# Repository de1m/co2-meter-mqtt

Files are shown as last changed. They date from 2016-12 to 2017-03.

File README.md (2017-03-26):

# CO2 Meter (mqtt)

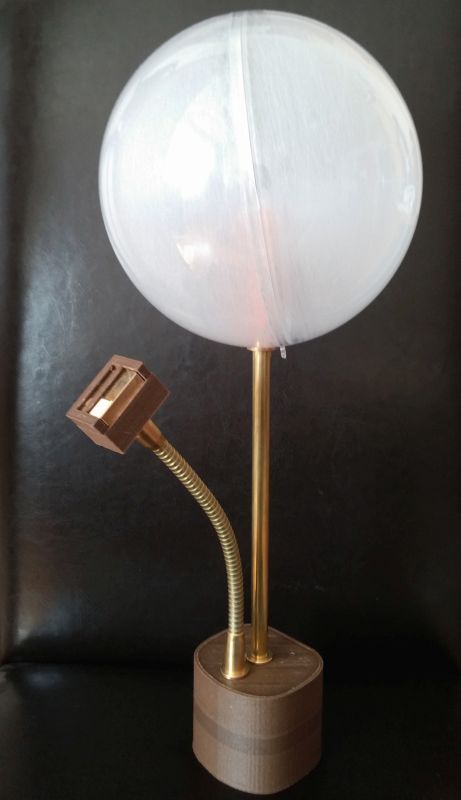
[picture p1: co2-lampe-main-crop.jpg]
main-image


## Description

In this project I've created a co2 sesor (mh-z19) with connection to a mqtt broker, so you cann send the co2 data to a mqtt broker. 

I've used the esp8266 12e version. 

Folder structure:
firmware - all files, that you do need to flash your esp8266 12e
pcb - board schema, pdfs. Imprtant: for the board you need a usb-connection board (show image board_top.jpg)
3d-models - 3d models for 3d printer, so you can print a case for pcb.

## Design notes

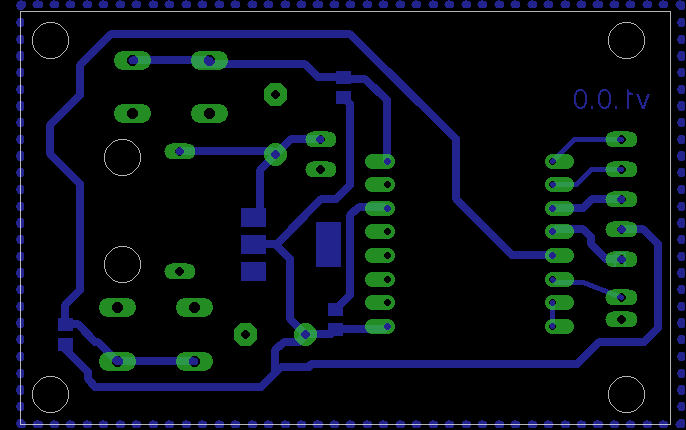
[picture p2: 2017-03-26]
pcb/board_screenshot.png

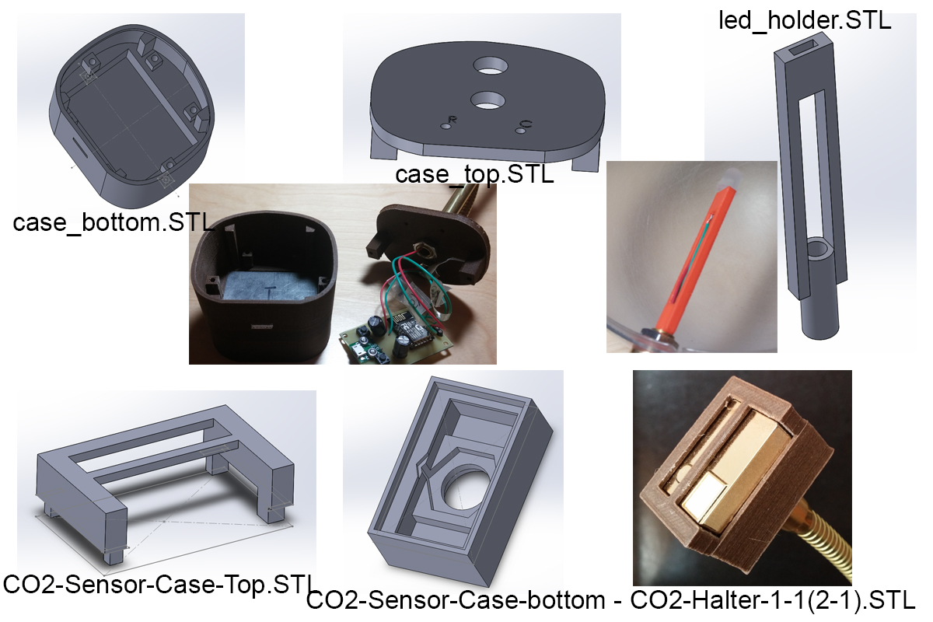
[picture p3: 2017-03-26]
3d_models/description.jpg

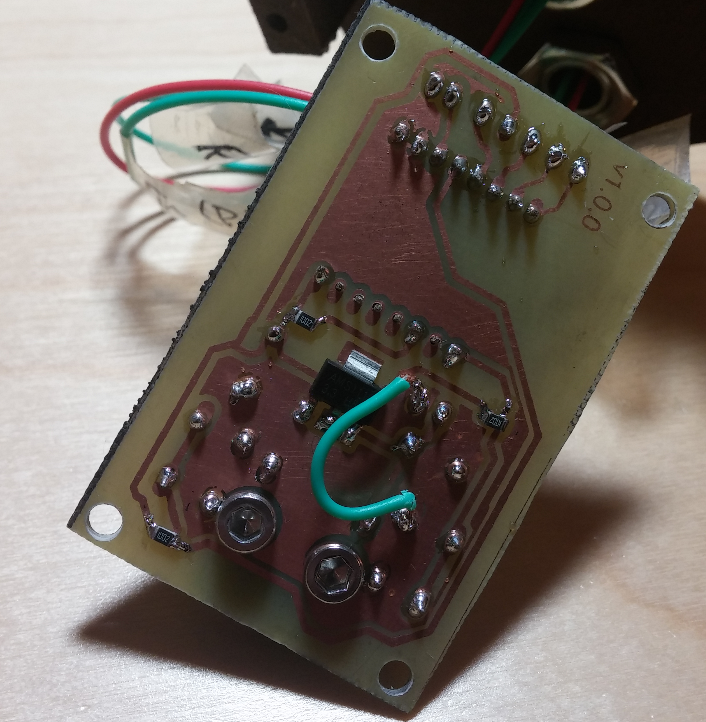
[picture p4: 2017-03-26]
pcb/board_foto_bottom.png

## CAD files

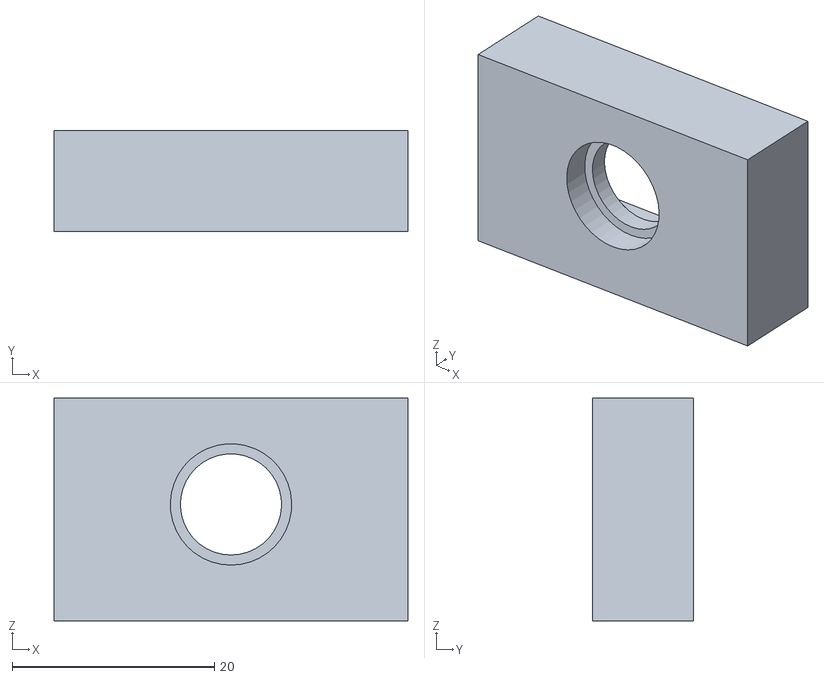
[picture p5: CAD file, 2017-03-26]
3d_models/CO2-Sensor-Case-bottom - CO2-Halter-2-1.STL
35.0 x 10.00 x 22.0

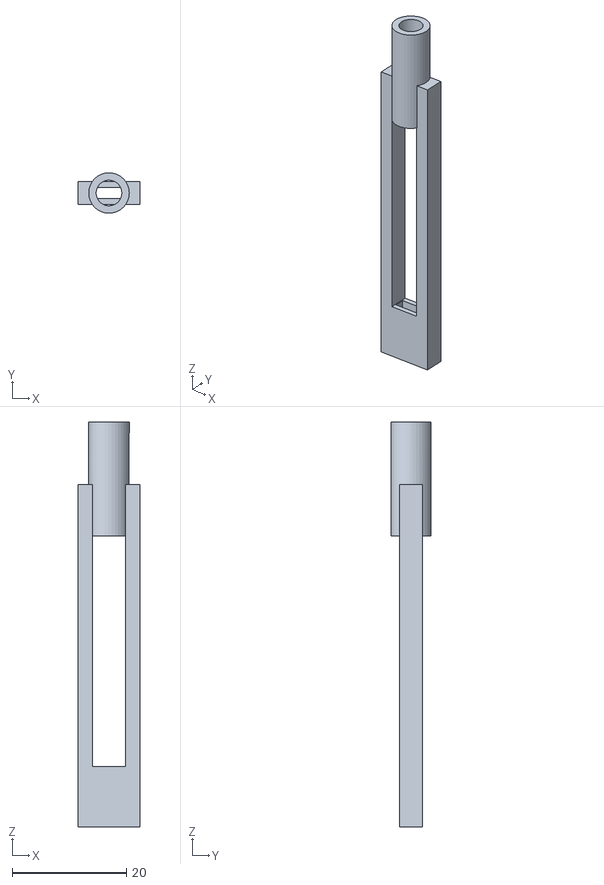
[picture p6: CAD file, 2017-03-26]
3d_models/led_holder.STL
10.9 x 7.09 x 71.0

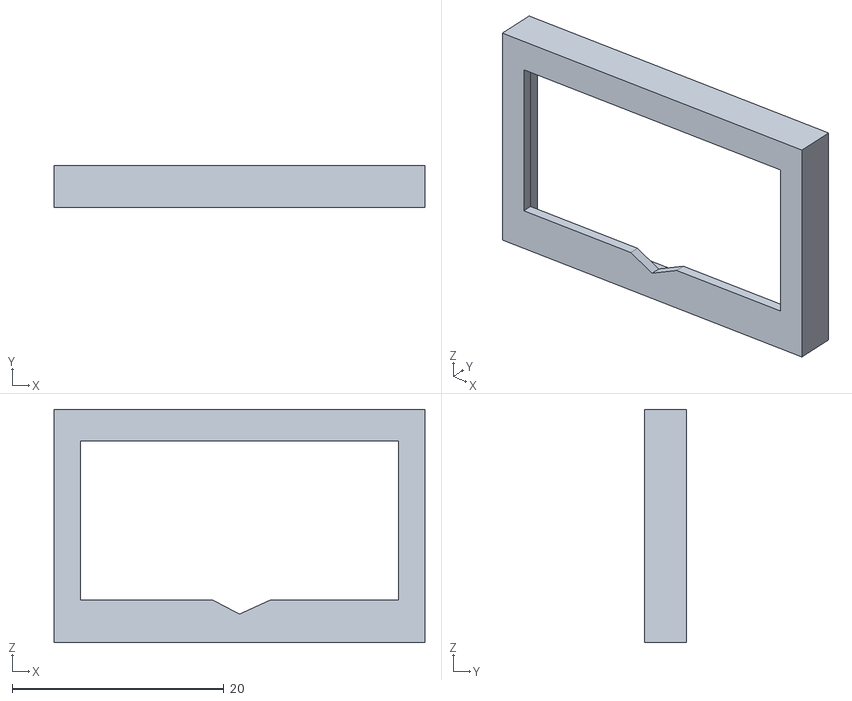
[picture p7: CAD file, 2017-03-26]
3d_models/CO2-Sensor-Case-bottom - CO2-Halter-1-1.STL
35.0 x 4.00 x 22.0

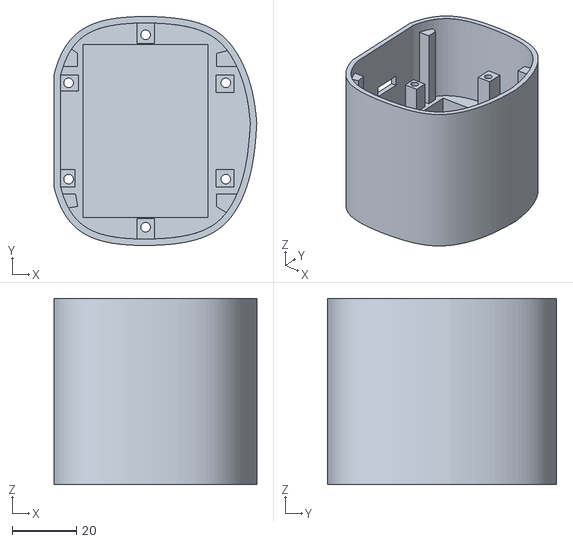
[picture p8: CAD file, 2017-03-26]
3d_models/case_bottom.STL
63.2 x 71.4 x 58.0

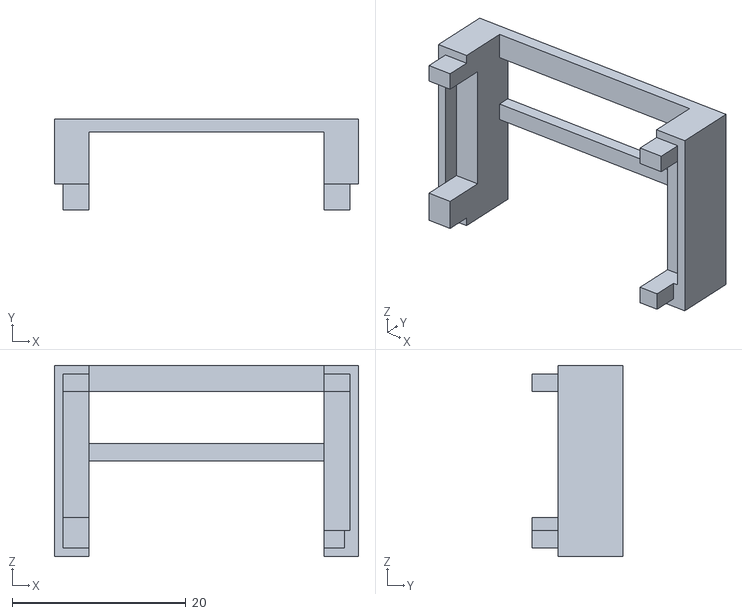
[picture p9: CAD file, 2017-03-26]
3d_models/CO2-Sensor-Case-Top.STL
35.0 x 10.5 x 22.0

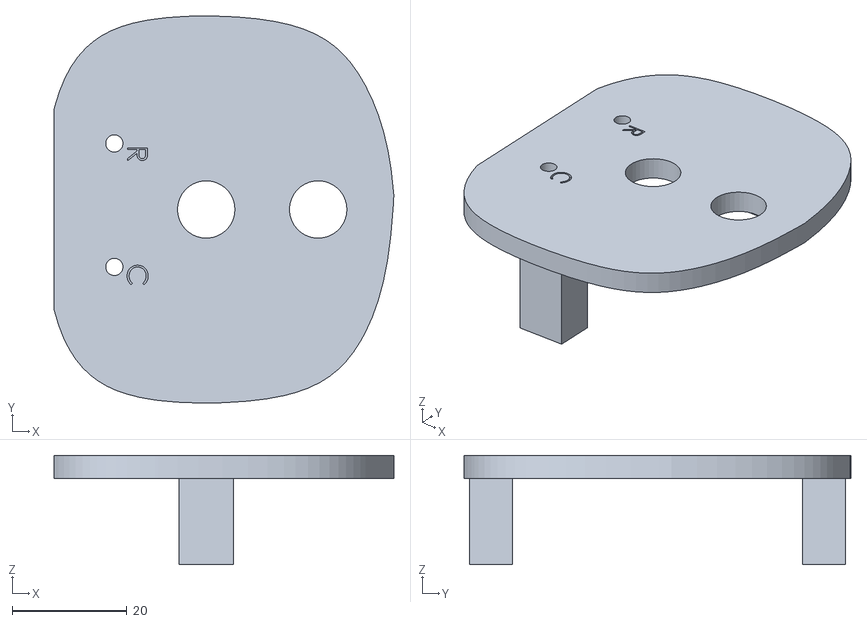
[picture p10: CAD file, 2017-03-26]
3d_models/case_top.STL
59.2 x 67.4 x 19.0

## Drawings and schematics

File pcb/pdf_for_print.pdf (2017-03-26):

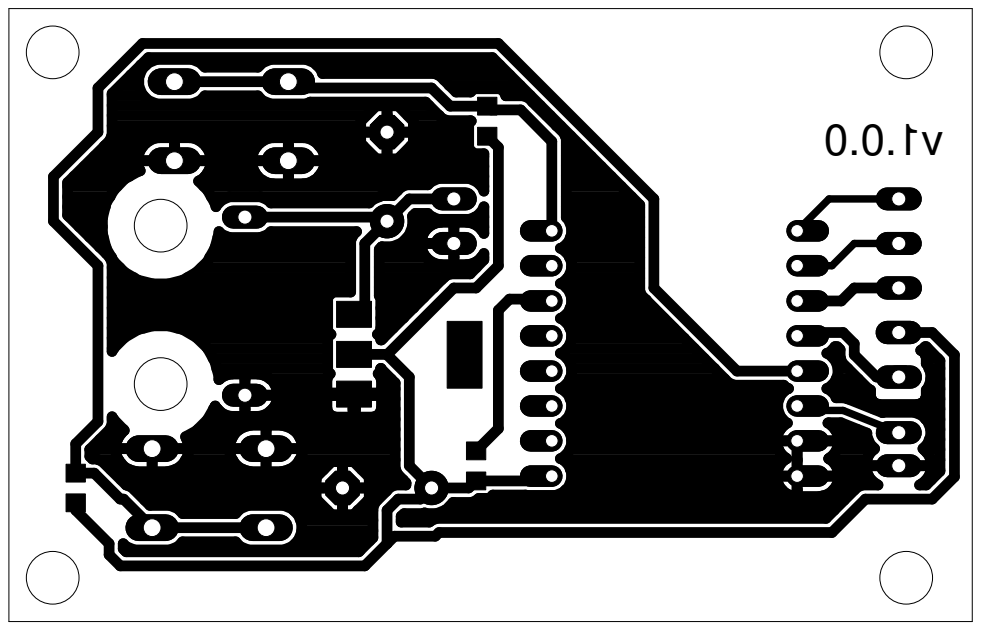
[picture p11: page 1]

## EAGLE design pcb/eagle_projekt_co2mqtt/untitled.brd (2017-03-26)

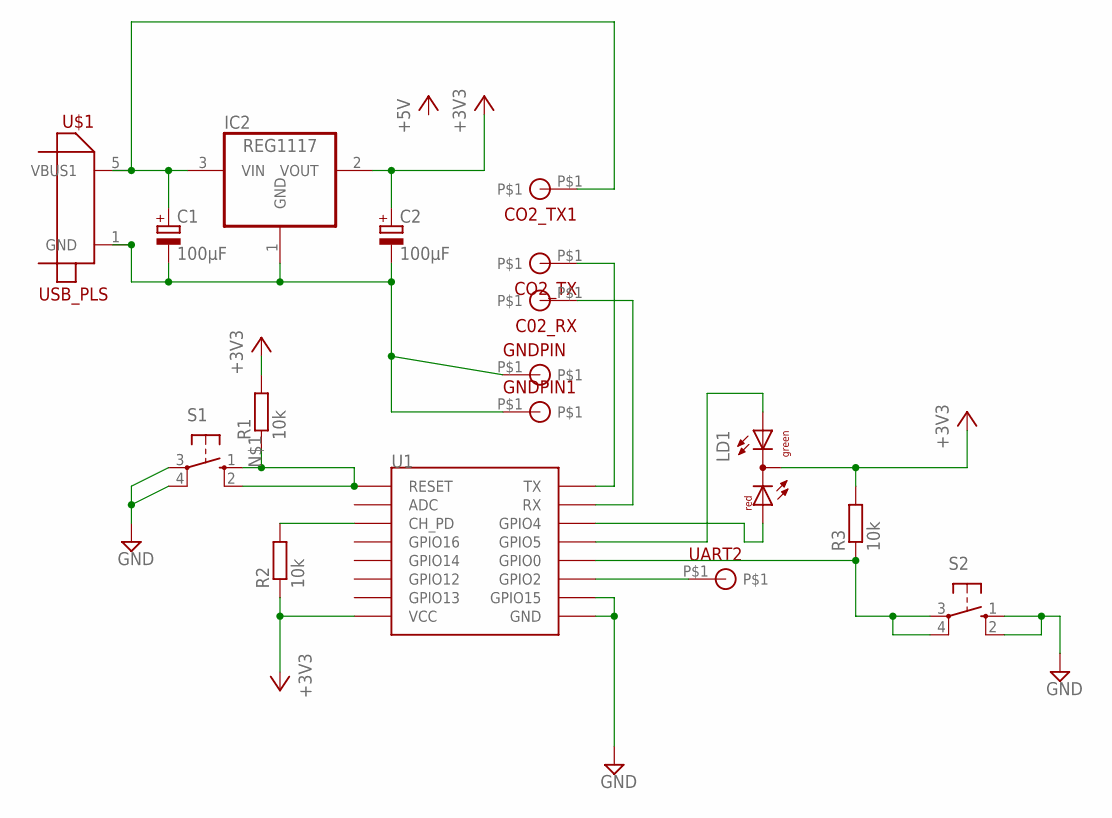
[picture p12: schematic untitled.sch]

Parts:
C1, C2: 100µF; E5-6
C02_RX: 1PIN
CO2_TX, CO2_TX1: 1PIN
GNDPIN, GNDPIN1: 1PIN
IC2: REG1117; SOT223
LD1: DUOLED-RG-C; DUOLED-C-5MM
R1, R2, R3: 10k; R0603
S1, S2: 10-XX; B3F-10XX
U1: ESP12
U$1: USB_PLS; USB_PLB
UART2: 1PIN

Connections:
+3V3: C2.+, IC2.2 (VOUT), LD1.C, R1.2, R2.1, R3.2, U1.VCC
+5V: C1.+, CO2_TX1.P$1, IC2.3 (VIN), U$1.5 (VBUS1)
GND: C1.-, C2.-, GNDPIN.P$1, GNDPIN1.P$1, IC2.1 (GND), S1.3, S1.4 (P1), S2.1 (S), S2.2 (S1), U1.GND, U1.GPIO15, U$1.1 (GND)
unnamed: R1.1, S1.1 (S), S1.2 (S1), U1.RESET
unnamed: R3.1, S2.3, S2.4 (P1), U1.GPIO0
unnamed: R2.2, U1.CH_PD
unnamed: LD1.AX (AG), U1.GPIO5
unnamed: LD1.AR, U1.GPIO4
unnamed: U1.GPIO2, UART2.P$1
RX: C02_RX.P$1, U1.RX
TX: CO2_TX.P$1, U1.TX

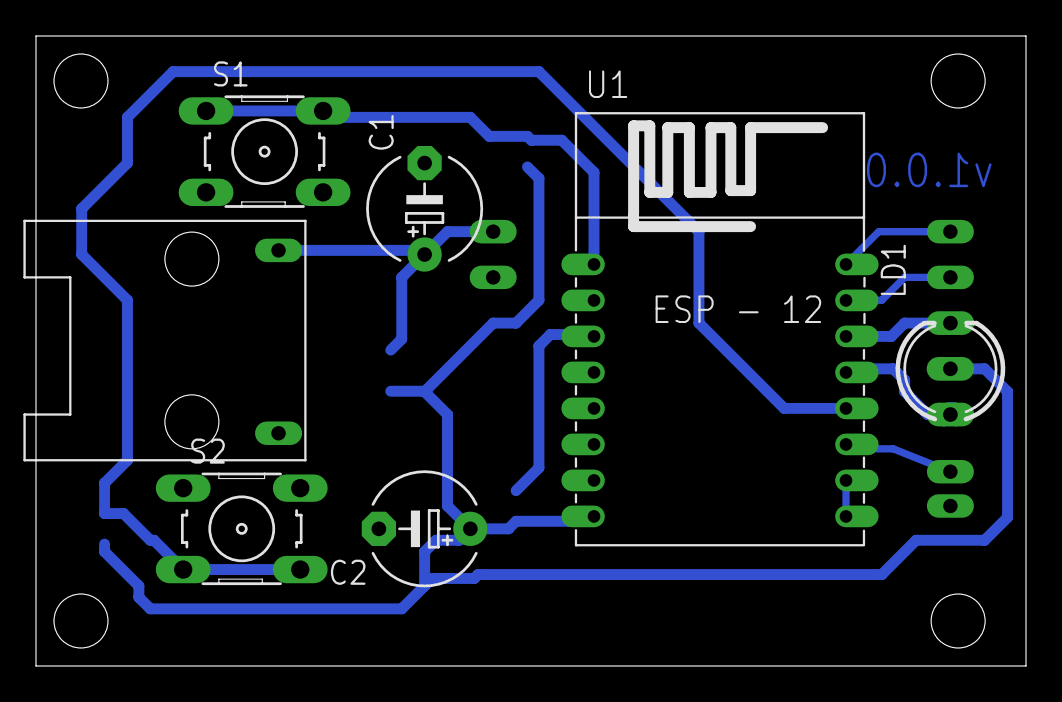
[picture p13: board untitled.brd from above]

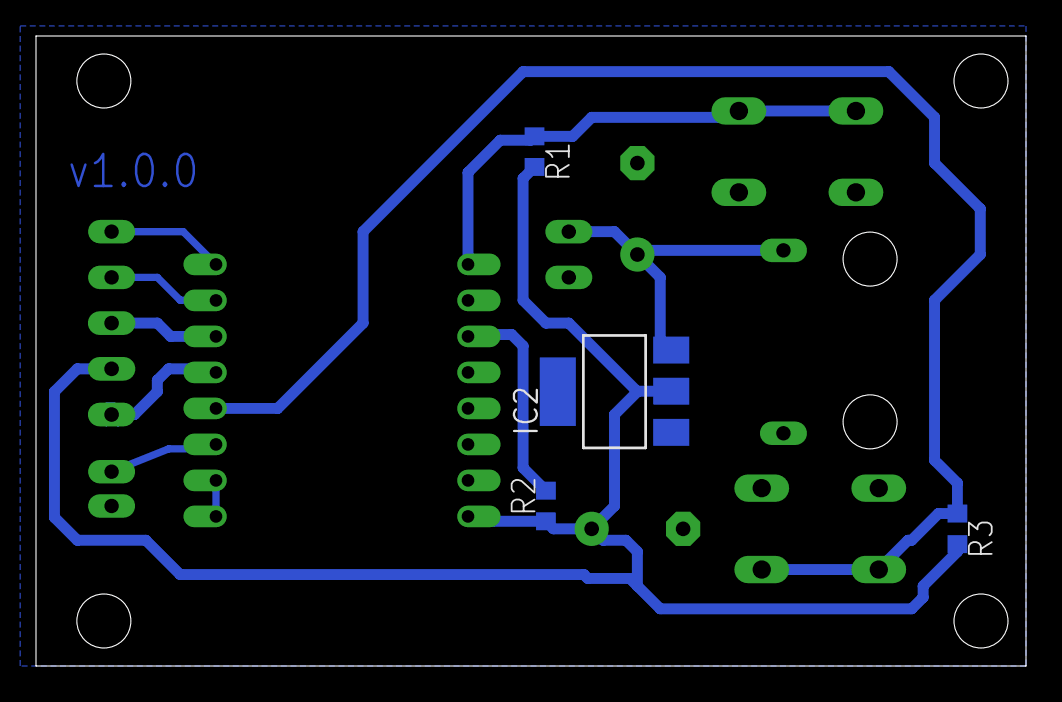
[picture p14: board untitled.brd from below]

Board: 2 copper layers, 55.0 x 35.0 mm, 17 parts (4 on the bottom side), 11 nets.

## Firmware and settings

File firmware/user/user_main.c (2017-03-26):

#include <ets_sys.h>
#include <osapi.h>
#include <ets_sys.h>
#include <os_type.h>
#include <gpio.h>
#include <mem.h>
#include <spi_flash.h>
#include "user_interface.h"
#include "config.h"
#include "mqtt.h"
#include "wifi.h"
#include "driver/uart.h"
#include <espconn.h>
#include "eagle_soc.h"
#include "fast_pwm.c"
#include "http.h"

#define BTN_CONFIG_GPIO 0
#define DEBUG

#define PPMMAX 2400
#define PPMMIN 400

//PWM Channels for LED (RG) //////////
#define PWM_2_OUT_IO_MUX PERIPHS_IO_MUX_GPIO4_U //R - Red
#define PWM_2_OUT_IO_NUM 4
#define PWM_2_OUT_IO_FUNC FUNC_GPIO4

#define PWM_3_OUT_IO_MUX PERIPHS_IO_MUX_GPIO5_U //G - Green
#define PWM_3_OUT_IO_NUM 5
#define PWM_3_OUT_IO_FUNC FUNC_GPIO5

#define PWM_CHANNEL 2
int ledinvert = 1; //1 = (+); 0 = (-)

uint32 io_info[][3] = {
  {PWM_2_OUT_IO_MUX, PWM_2_OUT_IO_FUNC, PWM_2_OUT_IO_NUM},
  {PWM_3_OUT_IO_MUX, PWM_3_OUT_IO_FUNC, PWM_3_OUT_IO_NUM}
};

/////////////////////////////////////

uint32 duty[] = {0};
uint32 freq = 65536;
uint32 pwmcurr[2] = {0,0};

MQTT_Client mqttClient;
MQTT_Client *clientptr;

static struct espconn esp_conn;

static esp_tcp esptcp;
struct wCLIENTCFG clientConf; //wifi config stuct
struct MQTTServer mqConf; //mqtt server config struct
struct co2sen co2Conf; //co2 sensor config struct
struct ledcnf ledConf; //led RG config struct

uint32 sendinterval;
char topic[128];
int onlyCO2 = 0;
int mIsConnected = 0;
int setLEDRed = 0;
int ledRED = 0;
int setLedOra = 0;

//for receive value from co2 sensor
const char cmd[9] = {0xFF,0x01,0x86,0x00,0x00,0x00,0x00,0x00,0x79}; //request
char ans[9]; //answer
uint8 counter = 0;

//times
os_timer_t DebounceTimer; //reset button debounce timer
os_timer_t SendDataTimer; //data send (MQTT) timer
os_timer_t ppmMaxLed; //if ppm > max value, then start this timer( for blink red led)
os_timer_t errorInputRed; //if error in html config input - red led on for 3 sec
os_timer_t tcpDisconnect; //call espconn_disconnect after 20ms
os_timer_t wifiConnCheck; //check connection to wifi
os_timer_t wifiErrorLedTimer; // blink led orange if wifi connection error


#define user_procTaskPrio        0
#define user_procTaskQueueLen    1
os_event_t user_procTaskQueue[user_procTaskQueueLen];

//reset vars
uint32_t timecount;
int timepressed = 0;

//receive co2 value from co2 sensor
static void ICACHE_FLASH_ATTR loop(os_event_t *events) {

  int c = uart0_rx_one_char();

  if(c != -1 ) {

	  ans[counter] = c;

	  //reset counter (after first boot)
	  if(ans[counter] == 0x86 && ans[counter-1] == 0xFF){
		  ans[0] = 0xFF;
		  ans[1] = 0x86;
		  counter = 1;
	  }
	  #ifdef DEBUG
		os_printf("counter: %d, ans: %02x \n", counter, ans[counter]);
	  #endif

	  counter++;
	  if(counter == 9){
		  counter = 0;
		  //start func to read co2 value
		  resolvCO2Value();
	  }
  }

  os_delay_us(100);
  system_os_post(user_procTaskPrio, 0, 0 );
}

//read co2 value and write this to 7seg display, LED and MQTT (if enabled)
void ICACHE_FLASH_ATTR resolvCO2Value(void){
	uint8 y;
	uint8 crc = 0;
	uint8 err = 0;
	uint32 co2value = 0;

    //unsigned int getMqttSett = readMqttSetting(&mqttInfo);
    unsigned int getMqttSett = spi_flash_read((LEDCONFADDR*SPI_FLASH_SEC_SIZE), (uint32*)&ledConf, sizeof(struct ledcnf));
	#ifdef DEBUG
		os_printf("LED PPMMMIN: %d\n", ledConf.ppmmin);
		os_printf("LED PPMMAX: %d\n", ledConf.ppmmax);
		os_printf("LED Brithness Co: %d\n", ledConf.brit);
	#endif

	counter = 0;

	//build checksum
	for(y = 1; y < 8; y++){
		crc += ans[y];
	}
	crc = 255 - crc;
	crc++;

	#ifdef DEBUG
		os_printf("Compare checksum from CO2(CRC) and calculated(CRCR)\n");
		os_printf("CRC: %d, CRCR: %d\n", ans[8], crc);
	#endif

	//if err wirte E001 to 7seg display, else send co2 to 7seg display
	if(!(ans[0] == 0xFF && ans[1] == 0x86 && ans[8] == crc)){
		//error
		err = 1;
	} else {

		uint32 ledR, ledG;

		//calculate co2 value from two bytes
		co2value = ans[2]*256 + ans[3];

		os_printf("CO2: %d\n", co2value);

		//calculate value RG (Red/Green) for RGB LED
	    if(co2value <= ledConf.ppmmin){
	        ledR = 0;
	        ledG = 255-ledR;

	        ledRED = 0;

	    } else {
	    	if(co2value >= ledConf.ppmmax){
		        ledR = 255;
		        ledG = 0;

		    	os_timer_disarm(&ppmMaxLed);
		    	os_timer_setfn(&ppmMaxLed, &blink_led_red, 0);
		    	os_timer_arm(&ppmMaxLed, 200, 1);

		    	ledRED = 1;
				#ifdef DEBUG
					os_printf("SET ledRED to: %d\n", ledRED);
				#endif

	    	} else {

	    		ledR = ((255)*(co2value-ledConf.ppmmin)*100/(ledConf.ppmmax - ledConf.ppmmin))/100;
	    		ledG = 255-ledR;

	    		ledRED = 0;
				#ifdef DEBUG
					os_printf("SET ledRED to: %d\n", ledRED);
				#endif
	    	}
	    }

		//correct
		ledR = ledR/ledConf.brit;
		ledG = ledG/ledConf.brit;

		#ifdef DEBUG
			os_printf("R: %d, G: %d\n", ledR, ledG);
		#endif

		if(ledRED == 0){
			pwm_write(ledR,ledG);
			#ifdef DEBUG
				os_printf("SET ledRED to: %d\nDISABLE ppmMaxLed\n", ledRED);
			#endif
			os_timer_disarm(&ppmMaxLed);
		}

	}

	//if mqtt disabled, do nothing, else send value to mqtt server
	if(onlyCO2 == 1){

		err = 0;

	} else {

		int len = 0;

		if(co2value < 1000){
			len = 3;
		} else if(co2value >= 1000) {
			len = 4;
		} else {
			len = 3;
		}

		char *buffer = (char*)os_malloc(sizeof(char)*(len+1));

		os_sprintf(buffer, "%d", co2value);

	    if(mIsConnected == 1){
	    	if(err == 1){
	    		MQTT_Publish(clientptr, topic, "err", len, mqConf.qos, 0);
	    	} else {
	    		MQTT_Publish(clientptr, topic, buffer, len, mqConf.qos, 0);
	    	}
	    } else {
	    	os_printf("mIsConnected: %d\n", mIsConnected);
	    }

	    err = 0;

	}
}

//timer for red blink(if co2 value is more then ppm max (default 2400))
void ICACHE_FLASH_ATTR blink_led_red(void *arg){

	//sed led to red;
	if(setLEDRed == 0){
		pwm_write(255/ledConf.brit,0);
		setLEDRed = 1;
	} else {
		pwm_write(0,0);
		setLEDRed = 0;
	}

}

//start as co2 sensor only (disply co2 value to 7seg)
void ICACHE_FLASH_ATTR startCo2only(void){
	#ifdef DEBUG
		os_printf("Start co2 only\n");
	#endif
	struct co2sen co2Sett;
	wifi_set_opmode(0);
    wipe_flash(1);

    unsigned int getCO2Sett = spi_flash_read((CO2CONFADDR*SPI_FLASH_SEC_SIZE), (uint32*)&co2Sett, sizeof(struct co2sen));
	#ifdef DEBUG
		os_printf("(17) - Read co2 interval setting: %d\n", co2Sett.interval);
	#endif

	pwm_write(0,50);

    onlyCO2 = 1;

    sendinterval = co2Sett.interval;

    //Start os task
    system_os_task(loop, user_procTaskPrio,user_procTaskQueue, user_procTaskQueueLen);
    system_os_post(user_procTaskPrio, 0, 0 );

    initSendTimer();

}

//start as ap for configuration
void ICACHE_FLASH_ATTR startAPMode(void) {

	//set name of wifi
	char const ssid_str[32] = "CO2.box";

	wifi_set_opmode(2);
	struct softap_config apconfig;
	os_memcpy(apconfig.ssid, &ssid_str, sizeof(ssid_str));

	apconfig.ssid_len = 0;
	apconfig.authmode = 0;
	apconfig.ssid_hidden = 0;
	apconfig.max_connection = 1;
	apconfig.beacon_interval = 100;

	if(wifi_softap_set_config(&apconfig))
	{
		#ifdef DEBUG
	   	   os_printf("\nRunning as AP. \nSSID: %s\n", apconfig.ssid);
		#endif

	} else {
		#ifdef DEBUG
			os_printf("\nERR: Cannot connect...\n");
		#endif
	}

	sta_init();

}

//connect to wifi and send co2 value to a mqtt server
void ICACHE_FLASH_ATTR startClient(void){
	#ifdef DEBUG
		os_printf("Start client\n");
	#endif

	struct MQTTServer mqttInfo;

	//delete co2 struct configuration from flash
    wipe_flash(2);
    onlyCO2 = 0;

    //unsigned int getMqttSett = readMqttSetting(&mqttInfo);
    unsigned int getMqttSett = spi_flash_read((MQTTCONFADDR*SPI_FLASH_SEC_SIZE), (uint32*)&mqConf, sizeof(struct MQTTServer));
	#ifdef DEBUG
		os_printf("(14) - Read from flash mqtt client id: %s\n", mqConf.clientid);
		os_printf("(15) - Read from flash mqtt user: %s\n", mqConf.user);
		os_printf("(16) - Read from flash mqtt pass: %s\n", mqConf.password);
		os_printf("(15) - Read from flash mqtt topic: %s\n", mqConf.topic);
		os_printf("(16) - Read from flash mqtt port: %d\n", mqConf.port);
		os_printf("(17) - Read from flash co2 interval: %d\n", mqConf.sendinterval);
	#endif

	sendinterval = mqConf.sendinterval;
	os_memcpy(topic, &mqConf.topic, sizeof(mqConf.topic));

	MQTT_InitConnection(&mqttClient, mqConf.server, mqConf.port, 0);

	if(mqConf.auth == 1){
		#ifdef DEBUG
			os_printf("Authentification enabled\n");
		#endif
		MQTT_InitClient(&mqttClient, mqConf.clientid, mqConf.user, mqConf.password, 120, 1);
	} else {
		#ifdef DEBUG
			os_printf("Authentification disabled\n");
		#endif
		MQTT_InitClient(&mqttClient, mqConf.clientid, 0, 0, 120, 1);
	}

	//registr mqtt callback functions
	MQTT_InitLWT(&mqttClient, "/lwt", "offline", 0, 0);
	MQTT_OnConnected(&mqttClient, mqttConnectedCb);
	MQTT_OnDisconnected(&mqttClient, mqttDisconnectedCb);
	MQTT_OnPublished(&mqttClient, mqttPublishedCb);

	WIFI_Connect(wifiConnectCb);

	//enable timer for check wifi connection(10sek)
	os_timer_disarm(&wifiConnCheck);
	os_timer_setfn(&wifiConnCheck, &check_wifi_stat, 0);
	os_timer_arm(&wifiConnCheck, 10*1000, 1); //10sec

    //Start os task
    system_os_task(loop, user_procTaskPrio,user_procTaskQueue, user_procTaskQueueLen);
    system_os_post(user_procTaskPrio, 0, 0 );

    //enable timer for send data
    initSendTimer();

}

//timer for send mqtt data and check co2
void ICACHE_FLASH_ATTR initSendTimer(void){

	os_timer_disarm(&SendDataTimer);
	os_timer_setfn(&SendDataTimer, &send_data_cb, 0);
	os_timer_arm(&SendDataTimer, sendinterval*1000, 1);

	#ifdef DEBUG
		os_printf("interval was set to %ld s.\n", sendinterval);
	#endif
}

//callback if wifi is connected
static void ICACHE_FLASH_ATTR wifiConnectCb(uint8_t status)
{
  if (status == STATION_GOT_IP) {
    MQTT_Connect(&mqttClient);
  } else {
    MQTT_Disconnect(&mqttClient);
  }
}

//function to parse GET request
static char ICACHE_FLASH_ATTR getValueOfKey(char *key, unsigned char maxlen, char *str, char *retval)
{
	unsigned char found = 0;
	char *keyptr = key;
	char prev_char = '\0';
	*retval = '\0';

	while( *str && *str!='\r' && *str!='\n' && !found )
	{
		if(*str == *keyptr)
		{
			if(keyptr == key && !( prev_char == '?' || prev_char == '&' ) )
			{
				str++;
				continue;
			}

			keyptr++;

			if (*keyptr == '\0')
			{
				str++;
				keyptr = key;
				if (*str == '=')
				{
					found = 1;
				}
			}
		}
		else
		{
			keyptr = key;
		}
		prev_char = *str;
		str++;
	}
	if(found == 1)
	{
		found = 0;
		while( *str && *str!='\r' && *str!='\n' && *str!=' ' && *str!='&' && maxlen>0 )
		{
			*retval = *str;
			maxlen--;
			str++;
			retval++;
			found++;
		}
		*retval = '\0';
	}
	return found;
}

//callback function if wifi client reconnected (AP mode). debug function
static void ICACHE_FLASH_ATTR sta_mode_recon_cb(void *arg, sint8 err)
{
    os_printf("STA Mode - Client reconnected\r\n");
}

//callback function if wifi client disconnected (AP mode). debug funtion
static void ICACHE_FLASH_ATTR sta_mode_discon_cb(void *arg)
{
    os_printf("STA Mode - Client disconnected\r\n");
}

//callback function if mqtt connected
static void ICACHE_FLASH_ATTR mqttConnectedCb(uint32_t *args)
{
	mIsConnected = 1;

	MQTT_Client* client = (MQTT_Client*)args;

	clientptr = (MQTT_Client*)args;
	#ifdef DEBUG
		os_printf("MQTT: Connected\r\n");
	#endif

	pwm_write(0,50);

}

//timer function if wifi or mqtt configuration not correct(blink orage/red)
void ICACHE_FLASH_ATTR blink_conf_err_led(void *arg){
	//sed led to red;
	if(setLedOra == 0){
		pwm_write(50,50);
		setLedOra = 1;
	} else {
		pwm_write(50,10);
		setLedOra = 0;
	}

}

//timer function to check wifi connection
void ICACHE_FLASH_ATTR check_wifi_stat(void *arg){
	uint8 wstat = wifi_station_get_connect_status();

	if(wstat == STATION_GOT_IP){ //ok
		os_timer_disarm(&wifiErrorLedTimer);
	} else {

		#ifdef DEBUG
			os_printf("Error wifi connection\n");
		#endif

		os_timer_disarm(&wifiErrorLedTimer);
		os_timer_setfn(&wifiErrorLedTimer, &blink_conf_err_led, 0);
		os_timer_arm(&wifiErrorLedTimer, 200, 1); //2sec
	}

	if(mIsConnected == 0){
		#ifdef DEBUG
			os_printf("Mqtt server not connected\n");
		#endif

		os_timer_disarm(&wifiErrorLedTimer);
		os_timer_setfn(&wifiErrorLedTimer, &blink_conf_err_led, 0);
		os_timer_arm(&wifiErrorLedTimer, 200, 1); //2sec

	} else {
		os_timer_disarm(&wifiErrorLedTimer);
		mIsConnected = 1;
	}
}

//callback function to send request to co2 sensor
void ICACHE_FLASH_ATTR send_data_cb(void *arg){

	//send requiest to co2 sensor
	uart0_tx_buffer(cmd, sizeof(cmd));

}

//callback function if mqtt is disconnected
static void ICACHE_FLASH_ATTR mqttDisconnectedCb(uint32_t *args){

	mIsConnected = 0;

	MQTT_Client* client = (MQTT_Client*)args;
	#ifdef DEBUG
	  os_printf("MQTT: Disconnected\r\n");
	#endif
}

//callback function if the co2 value was published to mqtt server
static void ICACHE_FLASH_ATTR mqttPublishedCb(uint32 *args)
{
	MQTT_Client* client = (MQTT_Client*)args;
	#ifdef DEBUG
	  os_printf("MQTT: Published\r\n");
	#endif
}

//callback function if answer was send to the client (AP mode/configuration)
void ICACHE_FLASH_ATTR tcpDisconnectCb(void *arg){

	#ifdef DEBUG
		os_printf("SEND DATA WAS OK2\n");
	#endif

	//disconnect web browser from sensor
	espconn_disconnect(arg);

	startMode();
}

//callback function if answer was send to the client (AP mode/configuration)2
void ICACHE_FLASH_ATTR sta_send_cb(void *arg){

	#ifdef DEBUG
		os_printf("SEND DATA WAS OK\n");
	#endif


	espconn_disconnect(arg);
}

//function to set timer to disconnect tcp connection (Port 80)
void ICACHE_FLASH_ATTR sta_noWifi_cb(void *arg){

	#ifdef DEBUG
		os_printf("START DISCONNECT TIMEOUT\n");
	#endif

	os_timer_disarm(&tcpDisconnect);
	os_timer_setfn(&tcpDisconnect, &tcpDisconnectCb, 0);
	os_timer_arm(&tcpDisconnect, 20, 0);
}

//function to display config warning setting (Led red)
void ICACHE_FLASH_ATTR errorConfigRed(void *arg){

	os_timer_disarm(&errorInputRed);
	pwm_write(50,50);
}

//callback function, if receive request on port tcp 80 (configuration website)
static void ICACHE_FLASH_ATTR sta_mode_recv_cb(void *arg, char *data, unsigned short len){

	//struct espconn *ptrespconn = (struct espconn *)arg;
	struct espconn *ptrespconn = arg;

	char tempInterval[32];
	int errCount = 0;

	#ifdef DEBUG
		os_printf("###### DStart ######\n");
		os_printf("Data: %s\n", data);
		os_printf("###### DStop ######\r\n");
	#endif

	//send configuration website
	if(os_strncmp(data, "GET / ", 6) == 0){
		espconn_send(ptrespconn, (uint8 *)formHtml, os_strlen(formHtml));
	}

	//parse configuration received from client
	if(os_strncmp(data, "GET /?int", 9) == 0){

		char wifiON[2];
		char tempAdvcd[2];
		char tempppmmin[4];
		char temppmmax[4];
		char tempbrit[1];

		//check advanced co2 sensor config
		//if not set, than set default
		if(getValueOfKey("adv", sizeof(tempAdvcd), data, tempAdvcd) <= 0){

			ledConf.ppmmin = PPMMIN;
			ledConf.ppmmax = PPMMAX;

		} else {

			//if advanced config is set, but ppm min is empty, than set default
			if(getValueOfKey("mmn", sizeof(tempppmmin), data, tempppmmin) <= 0){
				ledConf.ppmmin = PPMMIN;

			} else {
				ledConf.ppmmin = atoi(tempppmmin);
				if(ledConf.ppmmin <= 0){
					ledConf.ppmmin = PPMMIN;
				}
				if(ledConf.ppmmin >=5000){
					ledConf.ppmmin = 5000;
				}
			}

			if(getValueOfKey("mmx", sizeof(temppmmax), data, temppmmax) <= 0){
				ledConf.ppmmax = PPMMAX;
			} else {
				ledConf.ppmmax = atoi(temppmmax);
				if(ledConf.ppmmax <= 0){
					ledConf.ppmmax = PPMMAX;
				}
				if(ledConf.ppmmax >= 5000){
					ledConf.ppmmax = 5000;
				}
			}

		}

		if(getValueOfKey("brc", sizeof(tempbrit), data, tempbrit) <= 0){
			ledConf.brit = 2;
		} else {
			ledConf.brit = atoi(tempbrit);
		}

		//save led config
		spi_flash_erase_sector(LEDCONFADDR);
		unsigned int l = spi_flash_write((LEDCONFADDR*SPI_FLASH_SEC_SIZE), (uint32*)&ledConf, sizeof(struct ledcnf));
		if(l != SPI_FLASH_RESULT_OK){
			#ifdef DEBUG
				os_printf("Error write Led config to flash\n");
				os_printf("TEST1: %d\n", l);
			#endif
			errCount++;
		}

		//check if wifi & mqtt settings are activated
		if(getValueOfKey("wS", 2, data, wifiON) <= 0) {
			//wifi is not set

			#ifdef DEBUG
				os_printf("CO2 only\n");
			#endif

			// refresh interval
			if(getValueOfKey("int", sizeof(tempInterval), data, tempInterval) > 0){
				co2Conf.interval = atoi(tempInterval);
			} else {
				//set default
				co2Conf.interval = 120;
			}
			co2Conf.configsaved = 1;

			#ifdef DEBUG
				os_printf("CO2 Interval set to: %ld sec.\n", co2Conf.interval);
			#endif

			//write co2 config to flash
			spi_flash_erase_sector(CO2CONFADDR);
			unsigned int c = spi_flash_write(CO2CONFADDR*SPI_FLASH_SEC_SIZE, (uint32*)&co2Conf, sizeof(struct co2sen));

			if(c != SPI_FLASH_RESULT_OK){
				#ifdef DEBUG
					os_printf("Error write co2 sen config to flash\n");
					os_printf("TEST2: %d\n", c);
				#endif
				errCount++;
			} else {

				// delete mqtt configuration from flash
				int wstat = wipe_flash(DELWIFIMQTTCONF);
				if(wstat == 0){
					#ifdef DEBUG
						os_printf("Wipe MQTT and Wifi config successfull\n");
					#endif

					espconn_regist_sentcb(ptrespconn, sta_noWifi_cb);
					espconn_send(ptrespconn, (uint8 *)noWifiHtml, os_strlen(noWifiHtml));

				} else {
					os_printf("Wipe MQTT and Wifi config error\n");

					pwm_write(50,0);

			    	os_timer_disarm(&errorInputRed);
			    	os_timer_setfn(&errorInputRed, &errorConfigRed, 0);
			    	os_timer_arm(&errorInputRed, 5000, 0);

				}
			}

		} else {

			//wifi is set
			#ifdef DEBUG
				os_printf("Wifi and MQTT was set\n");
			#endif

			char tempQOS[1]; // temp char for MQTT QoS
			char tempport[5]; // temp char for MQTT Port
			char tempDhcp[2]; // temp char for dhcp setting (on/off)
			char tempAuth[2]; // temp char for auth setting (on/off)

			//convert wifi name and write to clientconf construct
			if(getValueOfKey("wf", sizeof(clientConf.ssid), data, clientConf.ssid) <= 0){
				#ifdef DEBUG
					os_printf("Value of SSID not correct: %s\n", clientConf.ssid);
				#endif
				errCount++;
			}

			//convert wifi pass from GET request
			if(getValueOfKey("ps", sizeof(clientConf.password), data, clientConf.password) <= 0){
				#ifdef DEBUG
					os_printf("Value of WIFI Pass not correct: %s\n", clientConf.password);
				#endif
				errCount++;
			}

			//check static ip or dhcp
			if(getValueOfKey("ipc", sizeof(tempDhcp), data, tempDhcp) <= 0){
				clientConf.dhcp = 1;
				#ifdef DEBUG
					os_printf("DHCP is set\n");
				#endif
			} else {
				#ifdef DEBUG
					os_printf("DHCP is NOT set\n");
				#endif

				//if static ip, convert values from GET request and write
				clientConf.dhcp = 0;
				getValueOfKey("ip", sizeof(clientConf.ip), data, clientConf.ip);
				getValueOfKey("net", sizeof(clientConf.netmask), data, clientConf.netmask);
				getValueOfKey("dn1", sizeof(clientConf.dns1), data, clientConf.dns1);
				getValueOfKey("dn2", sizeof(clientConf.dns2), data, clientConf.dns2);

				getValueOfKey("gw", sizeof(clientConf.gw), data, clientConf.gw);
			}
			clientConf.configsaved = 1;
			os_printf("\n");

			//mqtt client id
			if(getValueOfKey("mId", sizeof(mqConf.clientid), data, mqConf.clientid) <= 0){
				#ifdef DEBUG
					os_printf("Value of MQTT ID not correct: %s\n", mqConf.clientid);
				#endif
				errCount++;
			}

			//mqtt server address or ip
			if(getValueOfKey("mad", sizeof(mqConf.server), data, mqConf.server) <= 0){
				#ifdef DEBUG
					os_printf("Value of MQTT Server not correct: %s\n", mqConf.server);
				#endif
				errCount++;
			}

			//mqtt topic name
			if(getValueOfKey("mtpc", sizeof(mqConf.topic), data, mqConf.topic) <= 0){
				#ifdef DEBUG
					os_printf("Value of MQTT Topic not correct: %s\n", mqConf.topic);
				#endif
				errCount++;
			} else {

				//convert html string, "%2F" to "/"
				char *topicstr;
				int rpl = 0;
				topicstr = replace(mqConf.topic, "%2F", "/", &rpl);
				strcpy(mqConf.topic, topicstr);
			}

			//mqtt QoS
			if(getValueOfKey("mqs", sizeof(tempQOS), data, tempQOS) <= 0){
				mqConf.qos = 1;
			} else {

				int qost = atoi(tempQOS);

				if(qost >= 0 && qost <= 2){
					mqConf.qos = atoi(tempQOS);
				} else {
					mqConf.qos = 1;
				}

			}

			//mqtt send data interval == co2.sendinterval
			if(getValueOfKey("int", sizeof(tempInterval), data, tempInterval) <= 0){
				mqConf.sendinterval = 120;
			} else {
				mqConf.sendinterval = atoi(tempInterval);
			}

			//mqtt port (default 1833)
			if(getValueOfKey("mprt", sizeof(tempport), data, tempport) <= 0){
				mqConf.port = 1883;
			} else {
				mqConf.port = atoi(tempport);
			}

			//check if mqtt auth is enabled
			if(getValueOfKey("ath", sizeof(tempAuth), data, tempAuth) <= 0){
				//without auth
				#ifdef DEBUG
					os_printf("MQTT Auth is disabled\n");
				#endif
				mqConf.auth = 0;
			} else {
				//Auth true
				#ifdef DEBUG
					os_printf("MQTT Auth is enabled\n");
				#endif
				mqConf.auth = 1;

				//mqtt user
				if(getValueOfKey("mus", sizeof(mqConf.user), data, mqConf.user) <= 0){
					#ifdef DEBUG
						os_printf("Value of MQTT User not correct: %s\n", mqConf.user);
					#endif
					errCount++;
				}

				//mqtt pass
				if(getValueOfKey("mps", sizeof(mqConf.password), data, mqConf.password) <= 0){
					#ifdef DEBUG
						os_printf("Value of MQTT Pass not correct: %s\n", mqConf.password);
					#endif
					errCount++;
				}
			}

			//save wifi config
			spi_flash_erase_sector(WIFICONFADDR);
			unsigned int w = spi_flash_write((WIFICONFADDR*SPI_FLASH_SEC_SIZE),(uint32*)&clientConf, sizeof(struct wCLIENTCFG));
			if(w != SPI_FLASH_RESULT_OK){
				#ifdef DEBUG
					os_printf("Error write wifi config to flash\n");
					os_printf("TEST3: %d", w);
				#endif
				errCount++;
			}
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

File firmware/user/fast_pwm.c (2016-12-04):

/*
 * Copyright (C) 2016 Stefan Brüns <stefan.bruens@rwth-aachen.de>
 *
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
 * You should have received a copy of the GNU General Public License
 * along with this program; if not, write to the Free Software
 * Foundation, Inc., 51 Franklin St, Fifth Floor, Boston, MA  02110-1301 USA
 */

/* Set the following three defines to your needs */

#ifndef SDK_PWM_PERIOD_COMPAT_MODE
  #define SDK_PWM_PERIOD_COMPAT_MODE 0
#endif
#ifndef PWM_MAX_CHANNELS
  #define PWM_MAX_CHANNELS 8
#endif
#define PWM_DEBUG 0

/* no user servicable parts beyond this point */

#if SDK_PWM_PERIOD_COMPAT_MODE
#define PWM_PERIOD_TO_TICKS(x) (x * 0.2)
#define PWM_DUTY_TO_TICKS(x) (x * 5)
#else
#define PWM_PERIOD_TO_TICKS(x) (x)
#define PWM_DUTY_TO_TICKS(x) (x)
#endif

#include <c_types.h>
#include <pwm.h>
#include <eagle_soc.h>
#include <ets_sys.h>

// from SDK hw_timer.c
#define TIMER1_DIVIDE_BY_16             0x0004
#define TIMER1_ENABLE_TIMER             0x0080

struct pwm_phase {
	int32_t ticks;     ///< delay until next phase, in 200ns units
	uint16_t on_mask;  ///< GPIO mask to switch on
	uint16_t off_mask; ///< GPIO mask to switch off
};

/* Three sets of PWM phases, the active one, the one used
 * starting with the next cycle, and the one updated
 * by pwm_start. After the update pwm_next_set
 * is set to the last updated set. pwm_current_set is set to
 * pwm_next_set from the interrupt routine during the first
 * pwm phase
 */
typedef struct pwm_phase (pwm_phase_array)[PWM_MAX_CHANNELS + 2];
static pwm_phase_array pwm_phases[3];
static struct {
	struct pwm_phase* next_set;
	struct pwm_phase* current_set;
	uint8_t current_phase;
} pwm_state;

static uint32_t pwm_period;
static uint32_t pwm_period_ticks;
static uint32_t pwm_duty[PWM_MAX_CHANNELS];
static uint16_t gpio_mask[PWM_MAX_CHANNELS];
static uint8_t pwm_channels;

// 3-tuples of MUX_REGISTER, MUX_VALUE and GPIO number
typedef uint32_t (pin_info_type)[3];

struct gpio_regs {
	uint32_t out;         /* 0x60000300 */
	uint32_t out_w1ts;    /* 0x60000304 */
	uint32_t out_w1tc;    /* 0x60000308 */
	uint32_t enable;      /* 0x6000030C */
	uint32_t enable_w1ts; /* 0x60000310 */
	uint32_t enable_w1tc; /* 0x60000314 */
	uint32_t in;          /* 0x60000318 */
	uint32_t status;      /* 0x6000031C */
	uint32_t status_w1ts; /* 0x60000320 */
	uint32_t status_w1tc; /* 0x60000324 */
};
static struct gpio_regs* gpio = (void*)(0x60000300);

struct timer_regs {
	uint32_t frc1_load;   /* 0x60000600 */
	uint32_t frc1_count;  /* 0x60000604 */
	uint32_t frc1_ctrl;   /* 0x60000608 */
	uint32_t frc1_int;    /* 0x6000060C */
	uint8_t  pad[16];
	uint32_t frc2_load;   /* 0x60000620 */
	uint32_t frc2_count;  /* 0x60000624 */
	uint32_t frc2_ctrl;   /* 0x60000628 */
	uint32_t frc2_int;    /* 0x6000062C */
	uint32_t frc2_alarm;  /* 0x60000630 */
};
static struct timer_regs* timer = (void*)(0x60000600);

static void pwm_intr_handler(void)
{
	if ((pwm_state.current_set[pwm_state.current_phase].off_mask == 0) &&
	    (pwm_state.current_set[pwm_state.current_phase].on_mask == 0)) {
		pwm_state.current_set = pwm_state.next_set;
		pwm_state.current_phase = 0;
	}

	do {
		// force write to GPIO registers on each loop
		asm volatile ("" : : : "memory");

		gpio->out_w1ts = (uint32_t)(pwm_state.current_set[pwm_state.current_phase].on_mask);
		gpio->out_w1tc = (uint32_t)(pwm_state.current_set[pwm_state.current_phase].off_mask);

		uint32_t ticks = pwm_state.current_set[pwm_state.current_phase].ticks;

		pwm_state.current_phase++;

		if (ticks) {
			if (ticks >= 16) {
				// constant interrupt overhead
				ticks -= 9;
				timer->frc1_int &= ~FRC1_INT_CLR_MASK;
				WRITE_PERI_REG(&timer->frc1_load, ticks);
				return;
			}

			ticks *= 4;
			do {
				ticks -= 1;
				// stop compiler from optimizing delay loop to noop
				asm volatile ("" : : : "memory");
			} while (ticks > 0);
		}

	} while (1);
}

/**
 * period: initial period (base unit 1us OR 200ns)
 * duty: array of initial duty values, may be NULL, may be freed after pwm_init
 * pwm_channel_num: number of channels to use
 * pin_info_list: array of pin_info
 */
void ICACHE_FLASH_ATTR
pwm_init(uint32_t period, uint32_t *duty, uint32_t pwm_channel_num,
              uint32_t (*pin_info_list)[3])
{
	int i, j, n;

	pwm_channels = pwm_channel_num;
	if (pwm_channels > PWM_MAX_CHANNELS)
		pwm_channels = PWM_MAX_CHANNELS;

	for (i = 0; i < 3; i++) {
		for (j = 0; j < (PWM_MAX_CHANNELS + 2); j++) {
			pwm_phases[i][j].ticks = 0;
			pwm_phases[i][j].on_mask = 0;
			pwm_phases[i][j].off_mask = 0;
		}
	}
	pwm_state.current_set = pwm_state.next_set = 0;
	pwm_state.current_phase = 0;

	uint32_t all = 0;
	// PIN info: MUX-Register, Mux-Setting, PIN-Nr
	for (n = 0; n < pwm_channels; n++) {
		pin_info_type* pin_info = &pin_info_list[n];
		PIN_FUNC_SELECT((*pin_info)[0], (*pin_info)[1]);
		gpio_mask[n] = 1 << (*pin_info)[2];
		all |= 1 << (*pin_info)[2];
		if (duty)
			pwm_set_duty(duty[n], n);
	}
	GPIO_REG_WRITE(GPIO_OUT_W1TC_ADDRESS, all);
	GPIO_REG_WRITE(GPIO_ENABLE_W1TS_ADDRESS, all);

	pwm_set_period(period);

	ETS_FRC_TIMER1_INTR_ATTACH(pwm_intr_handler, NULL);
	TM1_EDGE_INT_ENABLE();

	RTC_CLR_REG_MASK(FRC1_INT_ADDRESS, FRC1_INT_CLR_MASK);
	RTC_REG_WRITE(FRC1_CTRL_ADDRESS,
		TIMER1_DIVIDE_BY_16 | TIMER1_ENABLE_TIMER);

	pwm_start();
}

__attribute__ ((noinline))
static uint8_t ICACHE_FLASH_ATTR
_pwm_phases_prep(struct pwm_phase* pwm)
{
	uint8_t n, phases;

	uint16_t off_mask = 0;
	for (n = 0; n < pwm_channels + 2; n++) {
		pwm[n].ticks = 0;
		pwm[n].on_mask = 0;
		pwm[n].off_mask = 0;
	}
	phases = 1;
	for (n = 0; n < pwm_channels; n++) {
		int32_t ticks = PWM_DUTY_TO_TICKS(pwm_duty[n]);
		if (ticks == 0) {
			pwm[0].off_mask |= gpio_mask[n];
		} else if (ticks >= pwm_period) {
			pwm[0].on_mask |= gpio_mask[n];
		} else {
			if (ticks < (pwm_period_ticks/2)) {
				pwm[phases].ticks = ticks;
				pwm[0].on_mask |= gpio_mask[n];
				pwm[phases].off_mask = gpio_mask[n];
			} else {
				pwm[phases].ticks = pwm_period_ticks - ticks;
				pwm[phases].on_mask = gpio_mask[n];
				pwm[0].off_mask |= gpio_mask[n];
			}
			phases++;
		}
	}
	pwm[phases].ticks = pwm_period_ticks;

	// bubble sort, lowest to hightest duty
	n = 2;
	while (n < phases) {
		if (pwm[n].ticks < pwm[n - 1].ticks) {
			struct pwm_phase t = pwm[n];
			pwm[n] = pwm[n - 1];
			pwm[n - 1] = t;
			if (n > 2)
				n--;
		} else {
			n++;
		}
	}

#if PWM_DEBUG
        int t = 0;
	for (t = 0; t <= phases; t++) {
		ets_printf("%d @%d:   %04x %04x\n", t, pwm[t].ticks, pwm[t].on_mask, pwm[t].off_mask);
	}
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

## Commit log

2016-12-04 fix error with htmlform length
    [user_main.c]
2016-12-08 add time couter to reset button, fix erros with write/read flash
    [user_main.c]
2016-12-18 add comments, fix error
    [user_main.c]
2017-03-26 add pcb, 3d models, readme
    [CO2-Sensor-Case-Top.STL, CO2-Sensor-Case-bottom - CO2-Halter-1-1.STL, CO2-Sensor-Case-bottom - CO2-Halter-2-1.STL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]

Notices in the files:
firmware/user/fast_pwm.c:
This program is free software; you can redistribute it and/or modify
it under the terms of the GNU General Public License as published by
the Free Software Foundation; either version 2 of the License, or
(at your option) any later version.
